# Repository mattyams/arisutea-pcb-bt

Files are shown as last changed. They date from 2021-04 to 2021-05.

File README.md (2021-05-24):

# VERY MUCH ALPHA BLUETOOTH VERSION!
# THIS IS STILL A WIP! NO GUARANTEES ON ANYTHING!
# Arisutea - Arisu Bluetooth Keyboard PCB
## Disclaimer: Use these files at your own risk.
アリステア PCB designed using KiCad. The layout was originally created by FateNozomi, inspired by Lyn's EM7 and TGR Alice with some modification. The layout was then modified by CorruptedJef and robotictomato to add Bluetooth using a Holyiot 18010, USB-C, ESD and to shift/add some keys. This inspired me to modify the layout further by adding the ability to swap your switches out whenever you want and to make some keys a little more permenant. I have designed many boards in the past but never a keyboard so this is my first crack at it and I figured why not go all out? If you notice any issue please open an issue and we can discuss!

Since the layout has been modified yet again I decided to give the project a new name, Arisutea, which translates to Alistair. Obviously keeping the theme running here. 

Key modifications to the PCB:
- Bluetooth using a Holyiot 18010.
- Added in Kailh Hotswap sockets.
- Addition of full backspace position, connected to switch 59 (row 0, column 13).
  - Removed switch 63 and repositioned switch 59 to add full backspace position.
- USB-C ESD rework.
- Added LED indicators for CAPS and NUM lock as well as layer.
- Updated JSON layout file for this particular keyboard.
- Original mounting holes have been widened to allow for M2+ standoffs to pass through the PCB to the FR4 plates linked below, so if you planned on using this in a different case other than the one provided or these plates....you might have a bad time. 

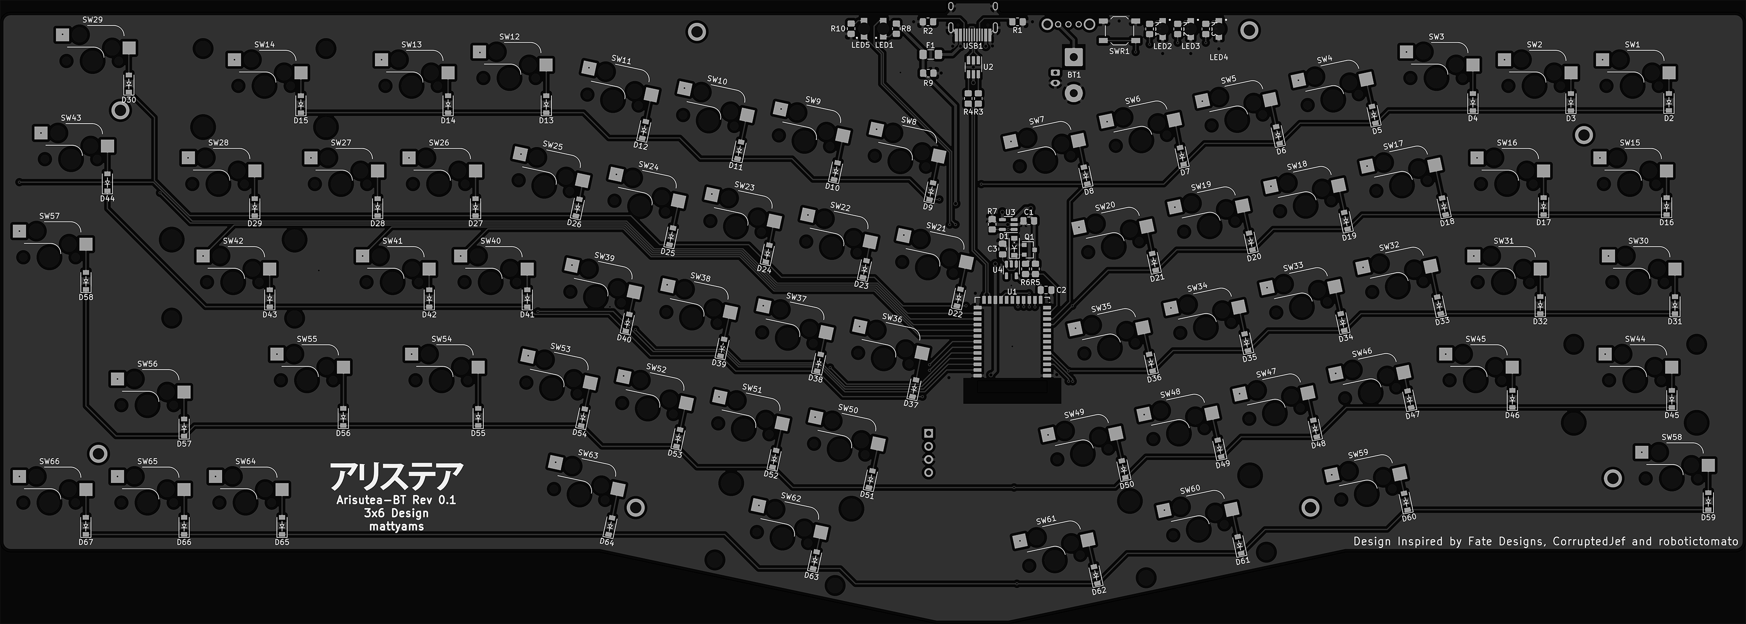
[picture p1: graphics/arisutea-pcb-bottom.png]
Arisutea

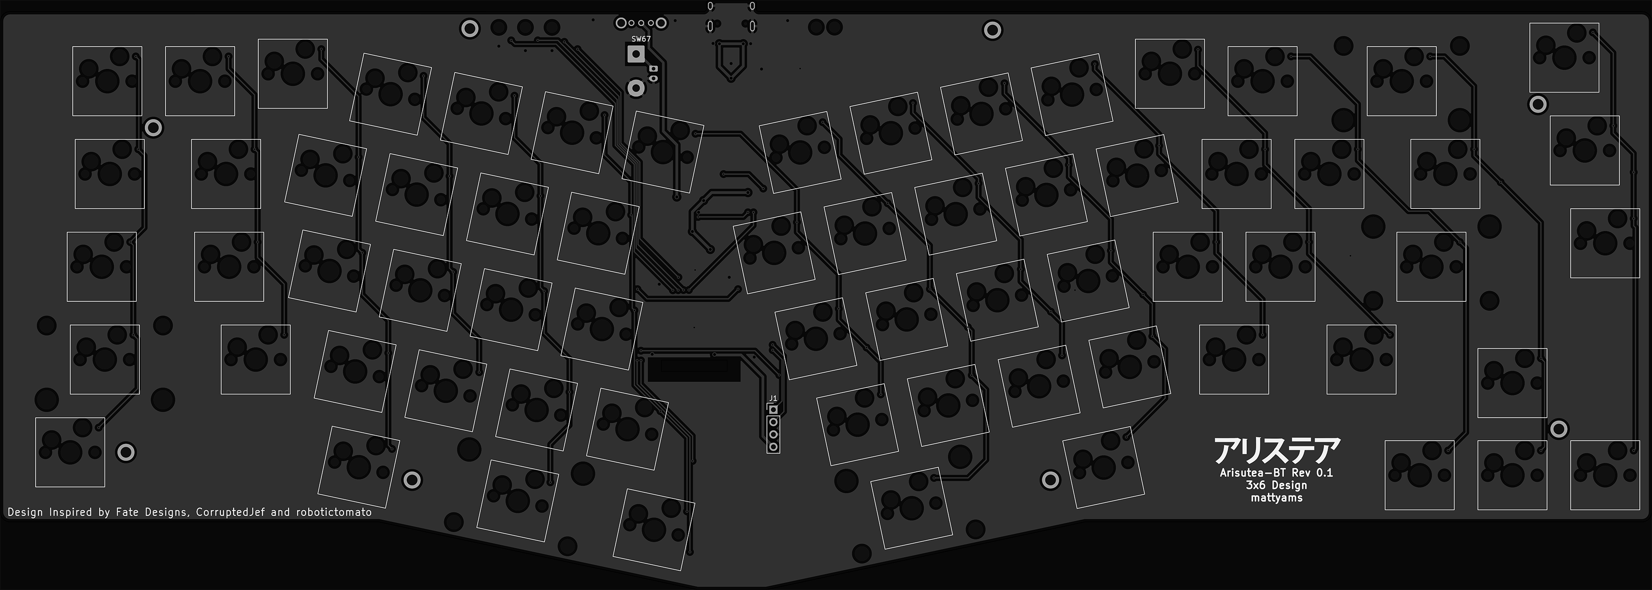
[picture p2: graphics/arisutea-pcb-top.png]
Arisutea-top


# ZMK Firmware
I plan to use ZMK for this board once I get it finalized.

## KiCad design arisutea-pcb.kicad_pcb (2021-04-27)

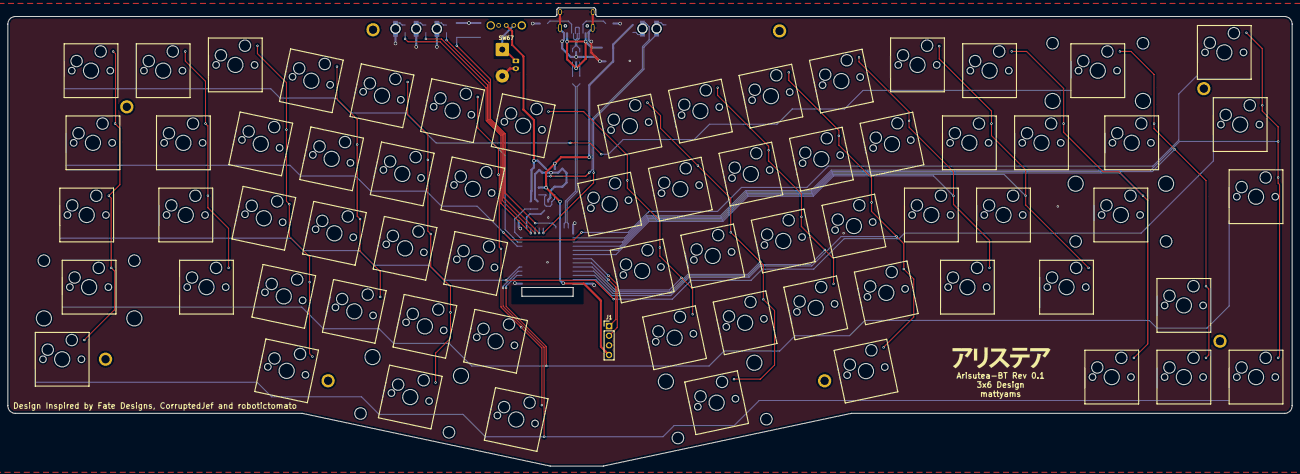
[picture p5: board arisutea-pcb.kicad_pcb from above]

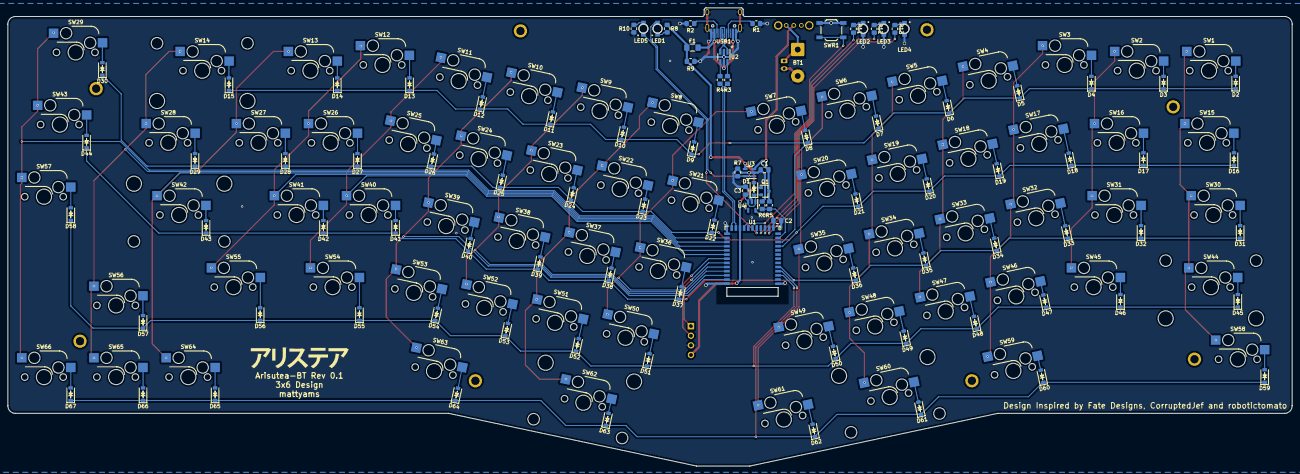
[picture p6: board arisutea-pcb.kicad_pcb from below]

Board: 2 copper layers, 339.1 x 121.0 mm, 176 parts (99 on the bottom side), 116 nets.

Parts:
BT1: Battery_Cell; Battery_Connector
BT2: Battery_Cell; JST_PH_S2B-PH-K_1x02_P2.00mm_Horizontal
C1: 4.7uF; C_0805_2012Metric_Pad1.18x1.45mm_HandSolder
C2, C3: 1uF; C_0805_2012Metric_Pad1.18x1.45mm_HandSolder
D1: 1N5819; D_SOD-123
D2, D3, D4, D5, D6, D7, D8, D9, D10, D11, D12, D13, D14, D15, D16, D17, D18, D19, D20, D21, D22, D23, D24, D25, D26, D27, D28, D29, D30, D31, D32, D33, D34, D35, D36, D37, D38, D39, D40, D41, D42, D43, D44, D45, D46, D47, D48, D49, D50, D51, D52, D53, D54, D55, D56, D57, D58, D59, D60, D61, D62, D63, D64, D65, D66, D67: D; D_SOD-123
F1: 500mA; Fuse_1206_3216Metric_Pad1.42x1.75mm_HandSolder
H1, H2, H3, H4, H5, H6, H7, H8: ThroughHole; Generic-Mounthole
J1: Conn_01x04; PinHeader_1x04_P2.54mm_Vertical
LED1: PWR_LED; LED_IN-S124ARUW
LED2: NUM_LOCK; LED_IN-S124ARUW
LED3: CAPS_LOCK; LED_IN-S124ARUW
LED4: FN_LED; LED_IN-S124ARUW
LED5: BAT_LED; LED_IN-S124ARUW
LOGO1, LOGO2: LOGO; arisutea_logo
Q1: AO3401A; SOT-23
R1, R2: 5k1; R_0805_2012Metric_Pad1.20x1.40mm_HandSolder
R3, R4: 22; R_0805_2012Metric_Pad1.20x1.40mm_HandSolder
R5: 806K; R_0805_2012Metric_Pad1.20x1.40mm_HandSolder
R6: 2M; R_0805_2012Metric_Pad1.20x1.40mm_HandSolder
R7, R9: 10K; R_0805_2012Metric_Pad1.20x1.40mm_HandSolder
R8: 1k; R_0805_2012Metric_Pad1.20x1.40mm_HandSolder
R10: 1K; R_0805_2012Metric_Pad1.20x1.40mm_HandSolder
R11, R12, R13: 470; R_0805_2012Metric_Pad1.20x1.40mm_HandSolder
SW1, SW2, SW3, SW4, SW5, SW6, SW7, SW8, SW9, SW10, SW11, SW12, SW13, SW16, SW17, SW18, SW19, SW20, SW21, SW22, SW23, SW24, SW25, SW26, SW27, SW29, SW31, SW32, SW33, SW34, SW35, SW36, SW37, SW38, SW39, SW40, SW41, SW43, SW45, SW46, SW47, SW48, SW49, SW50, SW51, SW52, SW53, SW54, SW56, SW57, SW59, SW61, SW63, SW64, SW65, SW66: SW_Push; SW_Hotswap_Kailh_1.00u
SW14: SW_Push; SW_Hotswap_Kailh_2.00u
SW15, SW28, SW58: SW_Push; SW_Hotswap_Kailh_1.50u
SW30, SW55: SW_Push; SW_Hotswap_Kailh_1.75u
SW42: SW_Push; SW_Hotswap_Kailh_2.25u_RevStab
SW44: SW_Push; SW_Hotswap_Kailh_2.25u
SW60: SW_Push; SW_Hotswap_Kailh_2.00u_RevStab
SW62: SW_Push; SW_Hotswap_Kailh_2.75u_RevStab
SW67: Switch; OS102011MA1QN1
SWR1: SW_Push; SW_SPST_TL3342
U1: nRF52840_holyiot_18010; nRF52840_holyiot_18010_HS_simple
U2: USBLC6-2SC6; SOT-23-6_Handsoldering
U3: TP4504; SOT-23-5
U4: AP2112K-3.3; SOT-23-5
USB1: HRO-TYPE-C-31-M-12-Type-C; USB_C_Receptacle_HRO_TYPE-C-31-M-12-HandSoldering

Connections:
CAPS_L: R12.2, U1.16
D+: R4.1, U1.24
D-: R3.1, U1.23
FN_L: R11.2, U1.17
GND: BT1.2, BT2.2, C1.1, C2.2, C3.2, J1.3, LED2.C, LED3.C, LED4.C, R1.1, R2.1, R6.1, R7.2, R9.2, R10.1, SWR1.1, U1.1, U1.25, U1.37, U2.2, U3.2, U4.2, USB1.1, USB1.12, USB1.13
NUM_L: R13.2, U1.15
unnamed: BT1.1, BT2.1, SW67.1
unnamed: C3.1, D1.1, Q1.2, U4.1, U4.3
unnamed: D2.2, SW1.2
unnamed: D3.2, SW2.2
unnamed: D4.2, SW3.2
unnamed: D5.2, SW4.2
unnamed: D6.2, SW5.2
unnamed: D7.2, SW6.2
unnamed: D8.2, SW7.2
unnamed: D9.2, SW8.2
unnamed: D10.2, SW9.2
unnamed: D11.2, SW10.2
unnamed: D12.2, SW11.2
unnamed: D13.2, SW12.2
unnamed: D14.2, SW13.2
unnamed: D15.2, SW14.2
unnamed: D16.2, SW15.2
unnamed: D17.2, SW16.2
unnamed: D18.2, SW17.2
unnamed: D19.2, SW18.2
unnamed: D20.2, SW19.2
unnamed: D21.2, SW20.2
unnamed: D22.2, SW21.2
unnamed: D23.2, SW22.2
unnamed: D24.2, SW23.2
unnamed: D25.2, SW24.2
unnamed: D26.2, SW25.2
unnamed: D27.2, SW26.2
unnamed: D28.2, SW27.2
unnamed: D29.2, SW28.2
unnamed: D30.2, SW29.2
unnamed: D31.2, SW30.2
unnamed: D32.2, SW31.2
unnamed: D33.2, SW32.2
unnamed: D34.2, SW33.2
unnamed: D35.2, SW34.2
unnamed: D36.2, SW35.2
unnamed: D37.2, SW36.2
unnamed: D38.2, SW37.2
unnamed: D39.2, SW38.2
unnamed: D40.2, SW39.2
unnamed: D41.2, SW40.2
unnamed: D42.2, SW41.2
unnamed: D43.2, SW42.2
unnamed: D44.2, SW43.2
unnamed: D45.2, SW44.2
unnamed: D46.2, SW45.2
unnamed: D47.2, SW46.2
unnamed: D48.2, SW47.2
unnamed: D49.2, SW48.2
unnamed: D50.2, SW49.2
unnamed: D51.2, SW50.2
unnamed: D52.2, SW51.2
unnamed: D53.2, SW52.2
unnamed: D54.2, SW53.2
unnamed: D55.2, SW54.2
unnamed: D56.2, SW55.2
unnamed: D57.2, SW56.2
unnamed: D58.2, SW57.2
unnamed: D59.2, SW58.2
unnamed: D60.2, SW59.2
unnamed: D61.2, SW60.2
unnamed: D62.2, SW61.2
unnamed: D63.2, SW62.2
unnamed: D64.2, SW63.2
unnamed: D65.2, SW64.2
unnamed: D66.2, SW65.2
unnamed: D67.2, SW66.2
unnamed: LED1.A, R8.2
unnamed: LED1.C, U3.1
unnamed: LED2.A, R11.1
unnamed: LED3.A, R12.1
unnamed: LED4.A, R13.1
unnamed: LED5.C, R10.2
unnamed: R1.2, USB1.4
unnamed: R2.2, USB1.10
unnamed: R3.2, U2.6
unnamed: R4.2, U2.4
unnamed: R7.1, U3.5
unnamed: U2.1, USB1.5, USB1.7
unnamed: U2.3, USB1.6, USB1.8
VBUS: D1.2, F1.2, J1.4, Q1.1, R8.1, R9.1, U1.22, U3.4
VDD_nRF: C2.1, U1.14, U4.5
bat_led: LED5.A, U1.18
bat_volt: R5.1, R6.2, U1.12
col0: SW1.1, SW15.1, SW30.1, SW44.1, SW58.1
col1: SW2.1, SW16.1, SW31.1, SW45.1
col2: SW3.1, SW17.1, SW32.1, SW46.1, SW59.1
col3: SW4.1, SW18.1, SW33.1, SW47.1
col4: SW5.1, SW19.1, SW34.1, SW48.1, SW60.1
col5: SW6.1, SW20.1, SW35.1, SW49.1, SW61.1
col6: SW7.1, SW21.1, SW36.1, SW50.1, U1.33
col7: SW8.1, SW22.1, SW37.1, SW51.1, SW62.1, U1.34
col8: SW9.1, SW23.1, SW38.1, SW52.1, U1.35
col9: SW10.1, SW24.1, SW39.1, SW53.1, SW63.1, U1.36
col10: SW11.1, SW25.1, SW40.1, SW54.1, U1.30
col11: SW12.1, SW26.1, SW41.1, SW55.1, U1.29
col12: SW13.1, SW27.1, SW42.1, SW64.1, U1.28
col13: SW14.1, SW28.1, SW56.1, SW65.1, U1.27
col14: SW29.1, SW43.1, SW57.1, SW66.1, U1.26
reset: SWR1.2, U1.21
row0: D2.1, D3.1, D4.1, D5.1, D6.1, D7.1, D8.1, D9.1, D10.1, D11.1, D12.1, D13.1, D14.1, D15.1, U1.11
row1: D16.1, D17.1, D18.1, D19.1, D20.1, D21.1, D22.1, D23.1, D24.1, D25.1, D26.1, D27.1, D28.1, D29.1, D30.1, U1.10
row2: D31.1, D32.1, D33.1, D34.1, D35.1, D36.1, D37.1, D38.1, D39.1, D40.1, D41.1, D42.1, D43.1, D44.1, U1.5
row3: D45.1, D46.1, D47.1, D48.1, D49.1, D50.1, D51.1, D52.1, D53.1, D54.1, D55.1, D56.1, D57.1, D58.1, U1.3
row4: D59.1, D60.1, D61.1, D62.1, D63.1, D64.1, D65.1, D66.1, D67.1, U1.4
swdclk: J1.2, U1.31
swdio: J1.1, U1.32
vbat: C1.2, Q1.3, R5.2, SW67.2, U3.3
vbus_usb: F1.1, U2.5, USB1.2, USB1.11

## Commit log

2021-04-04 correction to boxed case back plate
2021-04-13 underglow header placement moved a bit, add logos, move some components
    [arisutea-pcb.kicad_pcb]
2021-04-25 ibom and case revisions
2021-04-27 Initial upload of bluetooth version
    [Arisutea_FR4_Plate_Bottom.kicad_pcb, Arisutea_FR4_Plate_Top.kicad_pcb, arisutea-pcb.kicad_pcb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]
